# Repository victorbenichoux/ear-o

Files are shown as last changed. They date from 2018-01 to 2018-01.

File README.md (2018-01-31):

<p align="center">
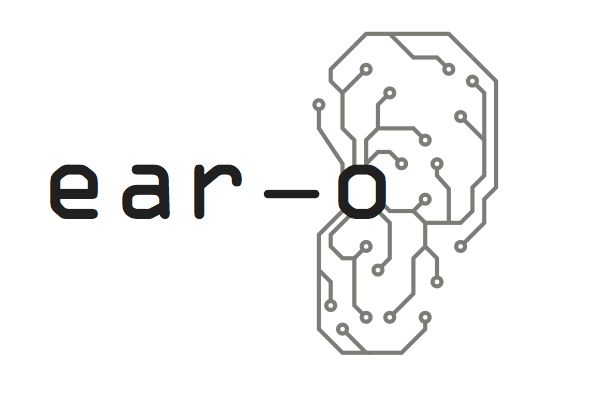
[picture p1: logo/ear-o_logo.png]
Github Logo

</p>

# Project

This project describes a hearing device that can be used as a tool for embedded digital signal processing. It is based on the Ezairo chip series by ON Semi.

## Contents

The repository contains some documentation and two designs:
* A development board
* A wearable earbud

## Built With

* [Eagle CAD](https://www.autodesk.com/products/eagle/overview) - For electronic circuits and board routing.
* [Fusion 360](https://www.autodesk.com/products/fusion-360/overview) - 3D models

## Authors

* **Victor Benichoux** - *electronics and software* - Researcher at [Institut Pasteur](https://research.pasteur.fr/en/member/victor-benichoux/). Contact me if you are interested in this project.
* **Albane Imbert** - *case design* - Head of the [fab lab](https://research.pasteur.fr/en/team/fab-lab/) at Institut Pasteur.

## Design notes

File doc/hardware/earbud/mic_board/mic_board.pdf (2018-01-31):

TITLE | VERSION
AUTHOR | DATE

HISTORY

PAGE | /1 | 1

## MICROPHONE BOARD

VICTOR BENICHOUX

v1.0

v1.0 : Initial release

16/01/2018

# MICP MICN MICS

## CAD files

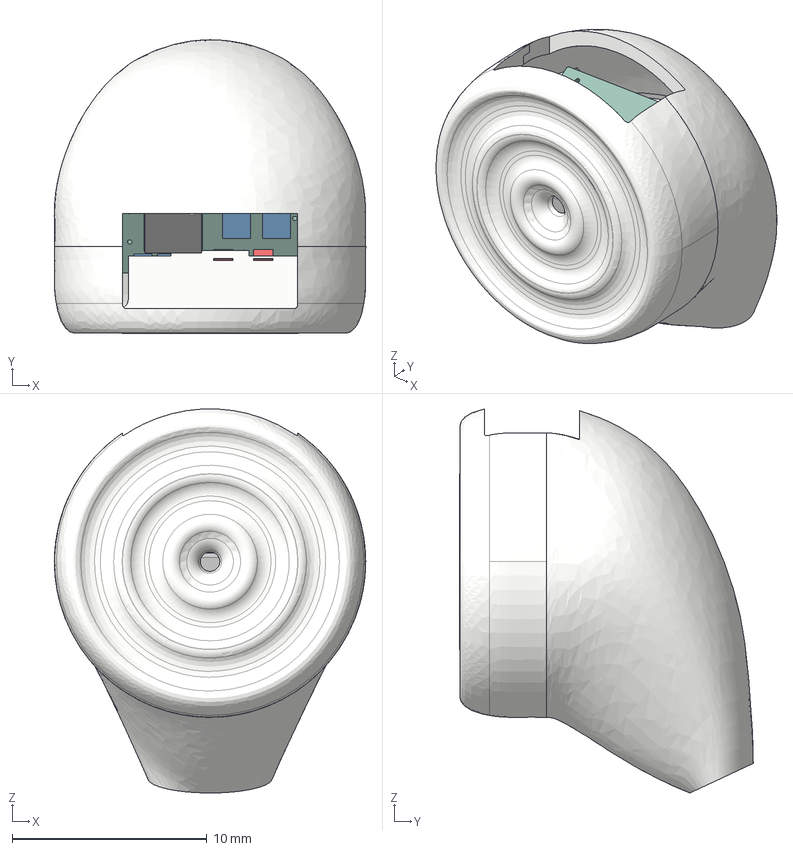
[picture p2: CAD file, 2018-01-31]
src/hardware/earbud/case/full_assembly.step
16.0 x 15.1 x 19.7 mm
Board
E7150-102A49-AG-MOD
ADXL362
220 uF x 2
12ohm x 6
RCVR
TEST-PAD-0.2 x 8
SINGLE-PAD x 12
Board_1
SINGLE-PADSQ x 3
mqm-32325-000_sw_asm(1)
Top Cap
Bottom cap

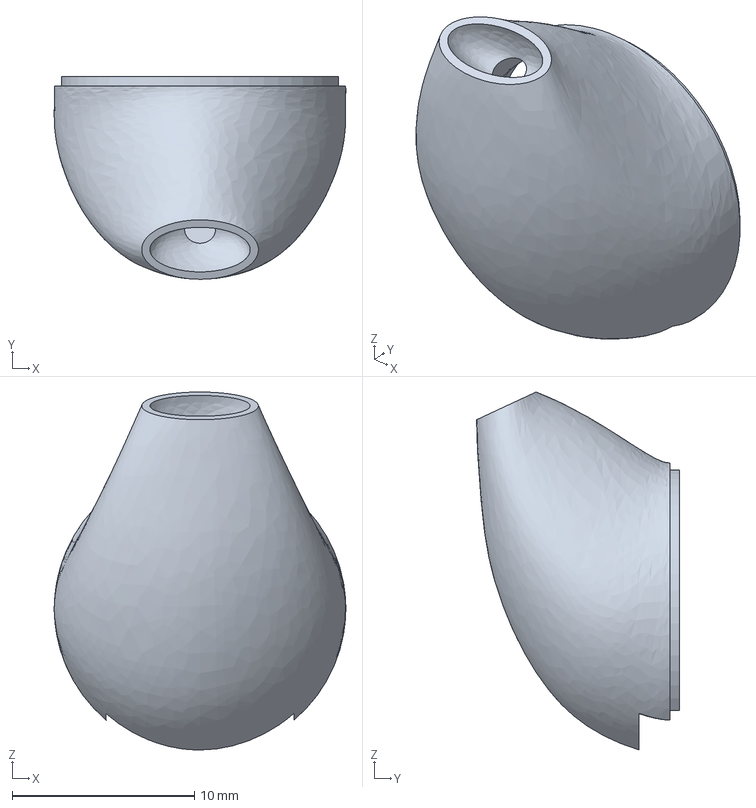
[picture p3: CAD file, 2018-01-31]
src/hardware/earbud/case/bottom_cap.step
16.0 x 11.1 x 19.6 mm

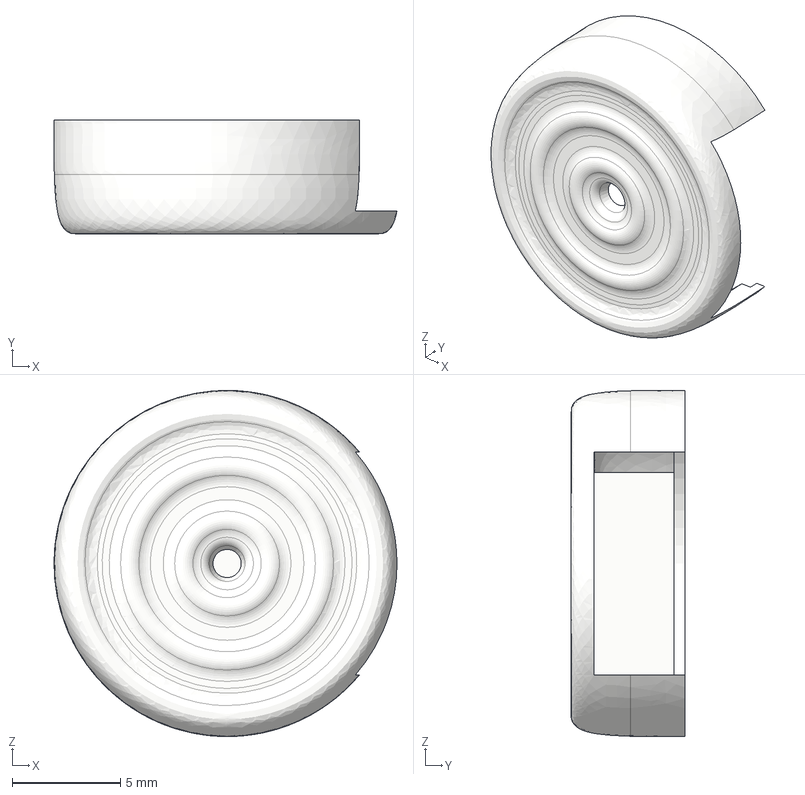
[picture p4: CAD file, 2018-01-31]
src/hardware/earbud/case/top_cap.step
15.9 x 5.27 x 16.0 mm

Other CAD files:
src/hardware/earbud/case/bottom_cap.stl
src/hardware/earbud/case/top_cap.stl

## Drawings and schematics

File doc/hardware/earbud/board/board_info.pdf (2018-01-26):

BOTTOM VIEW | TOP VIEW

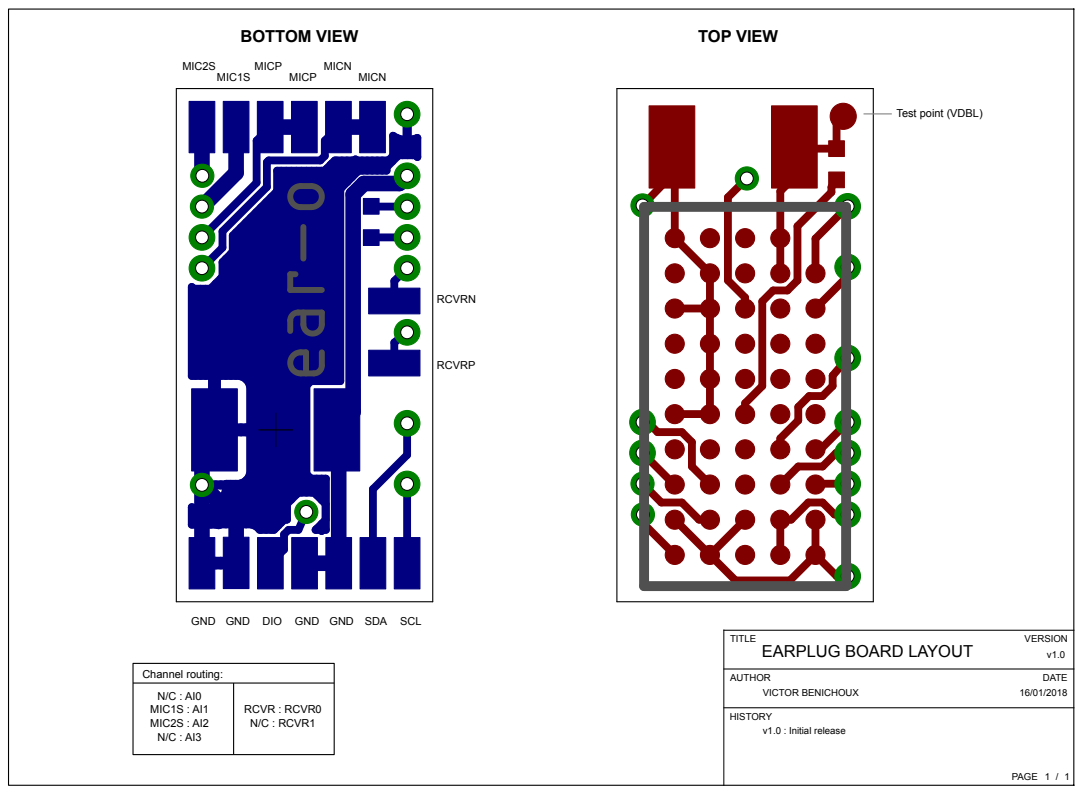
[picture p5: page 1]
TITLE; VERSION; AUTHOR; DATE; HISTORY; PAGE; VICTOR BENICHOUX; v1.0 : Initial release; RCVRP; RCVRN; MIC2S; MIC1S; MICN; MICP; N/C : AI0 MIC1S : AI1 MIC2S : AI2 N/C : AI3; Channel routing:; RCVR : RCVR0 N/C : RCVR1

Test point (VDBL)

GND GND DIO GND GND SDA SCL

EARPLUG BOARD LAYOUT

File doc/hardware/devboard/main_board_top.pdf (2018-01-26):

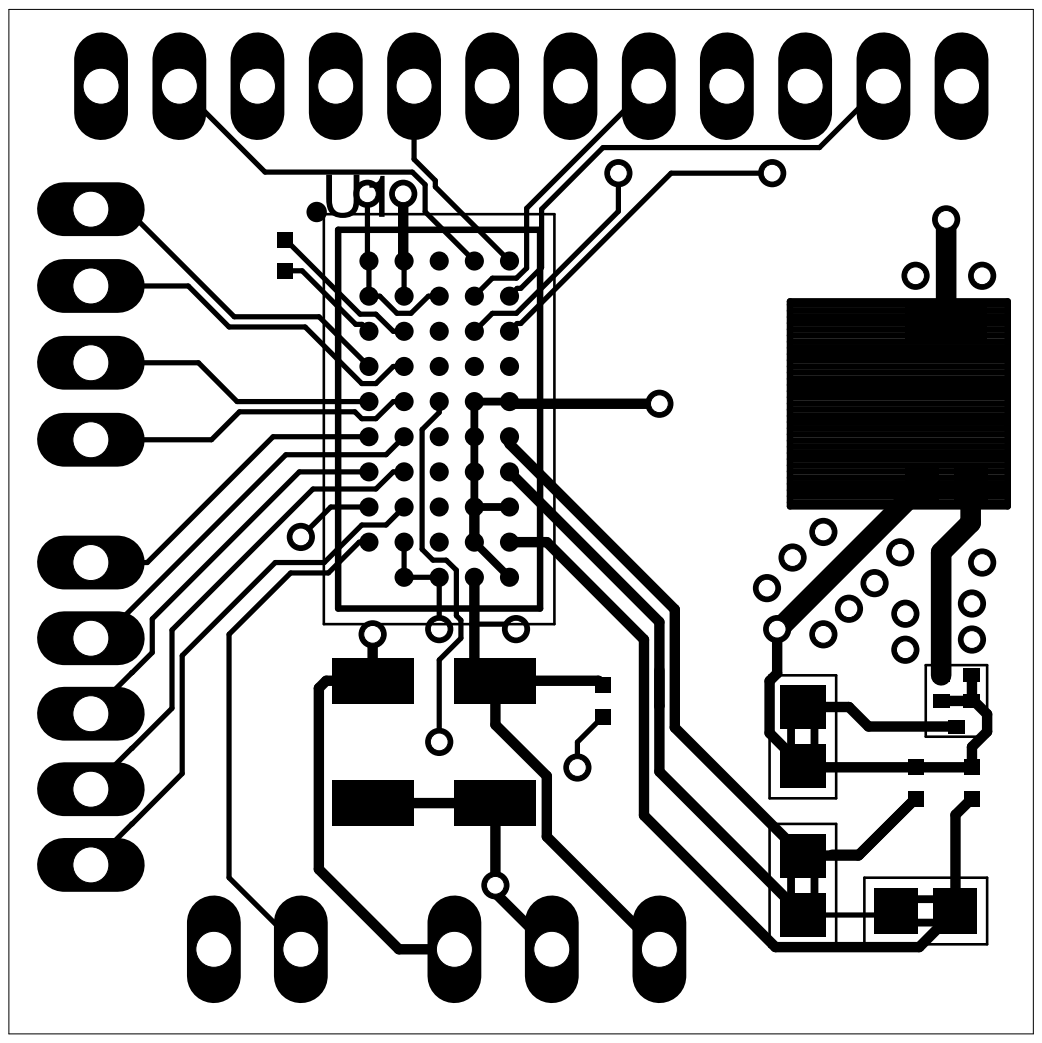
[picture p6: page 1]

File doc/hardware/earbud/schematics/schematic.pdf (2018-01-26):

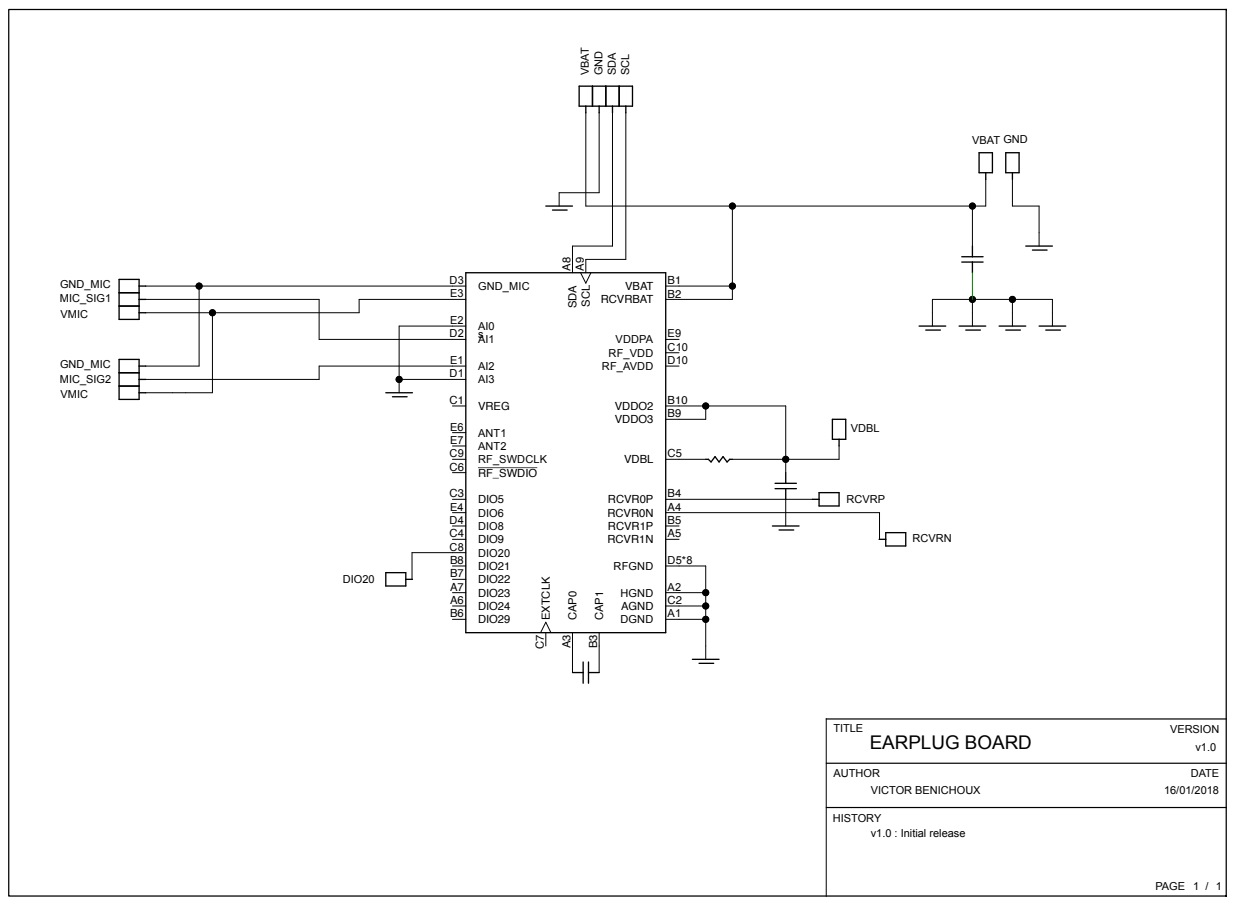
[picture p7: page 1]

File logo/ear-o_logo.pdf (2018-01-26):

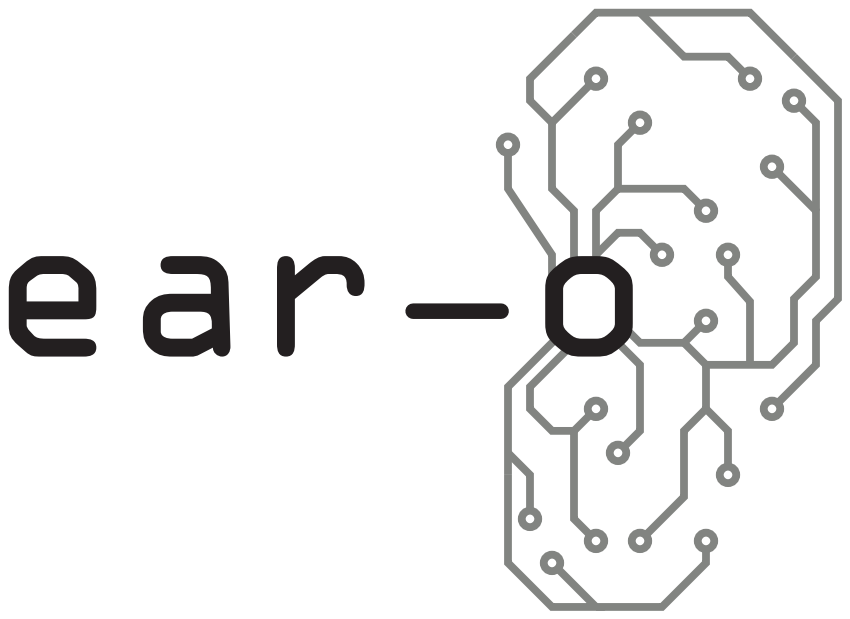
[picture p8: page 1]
ear o ear o

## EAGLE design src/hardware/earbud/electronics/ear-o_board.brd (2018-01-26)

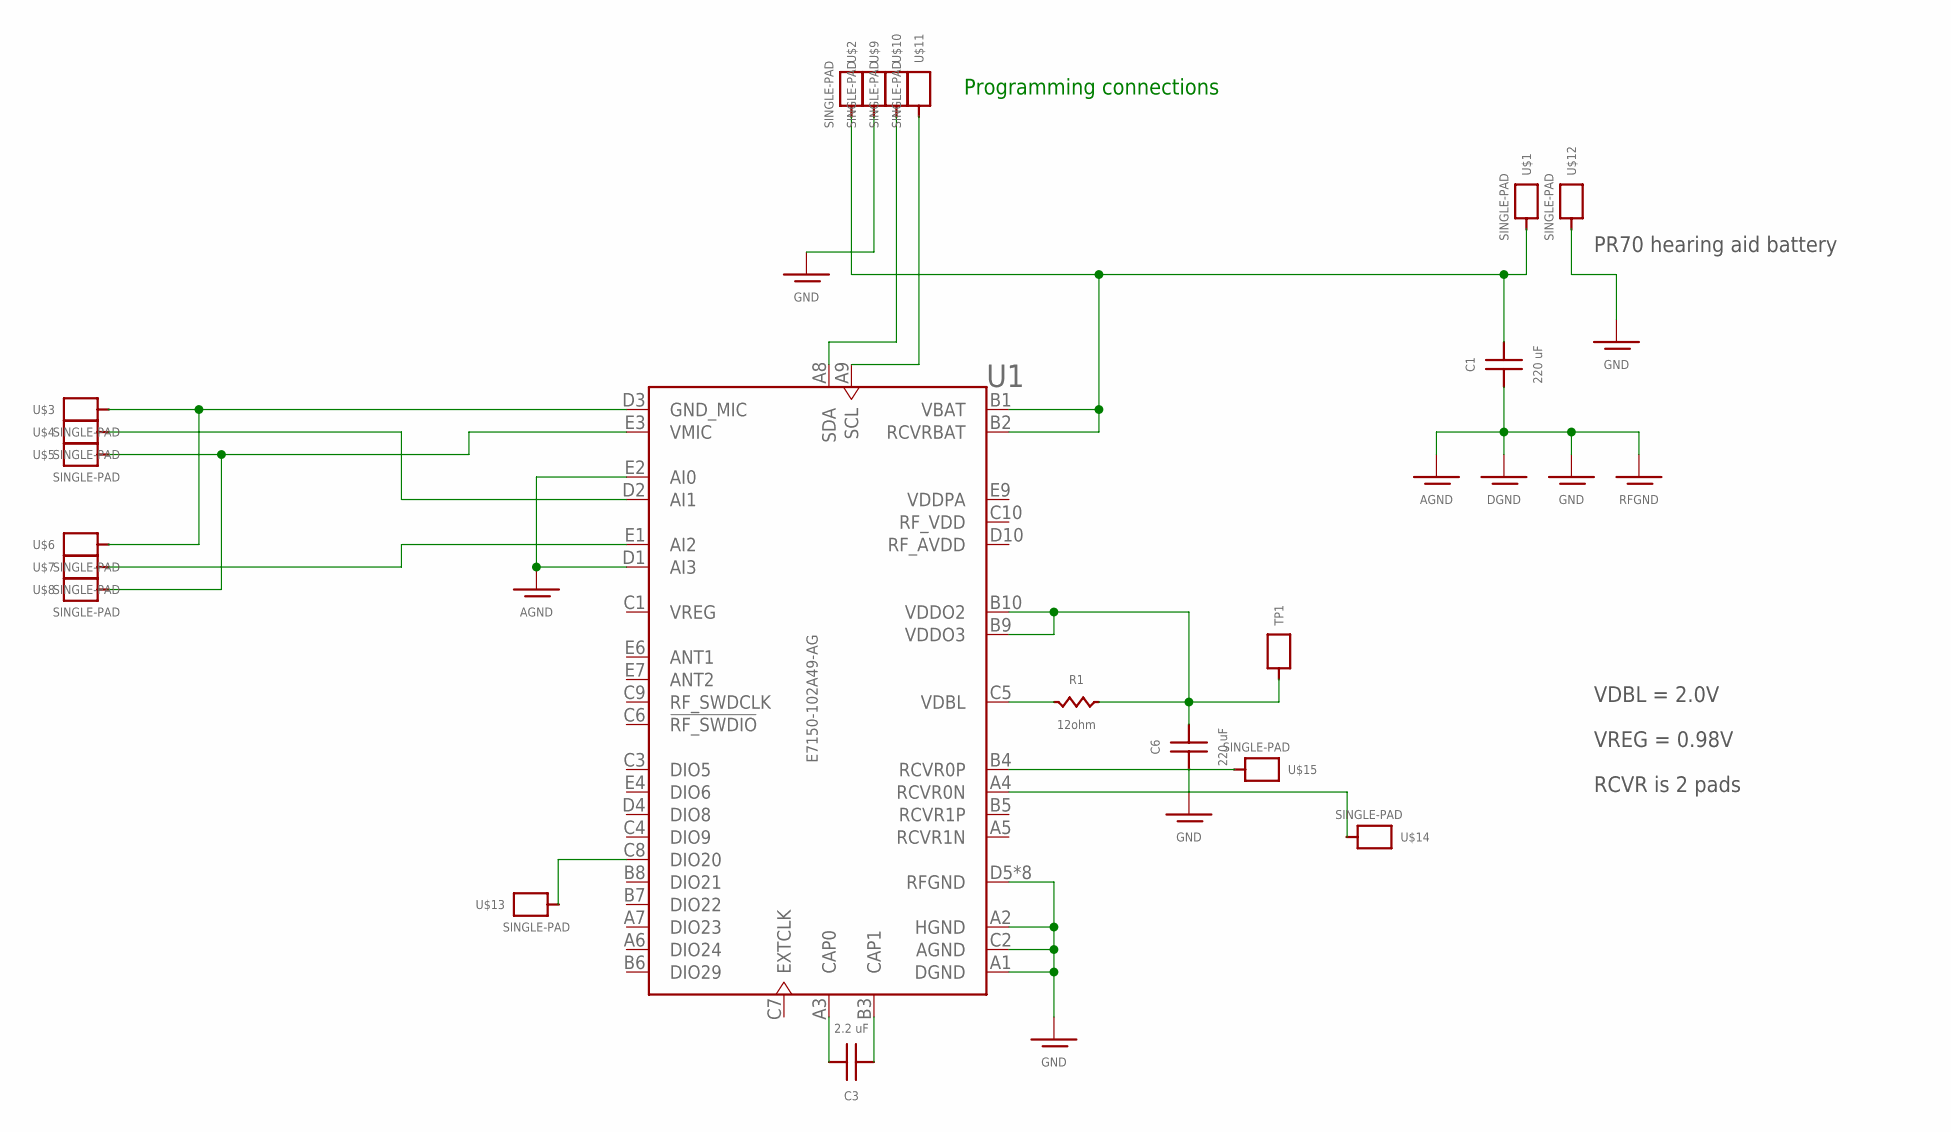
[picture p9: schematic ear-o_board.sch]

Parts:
C1, C6: 220 uF; 1206
C3: 2.2 uF; 0201
R1: 12ohm; 0201
TP1: TEST-POINT; TEST-PAD-0.2
U1: E7150-102A49-AG; BGA49C69P10X5_739X394X178
U$1, U$2, U$3, U$4, U$5, U$6, U$7, U$8, U$9, U$10, U$11, U$12, U$13, U$14, U$15: SINGLE-PAD

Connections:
1.4V: C1.P$2 (2), U1.B1 (VBAT), U1.B2 (RCVRBAT), U$1.P$1, U$2.P$1
GND: C1.P$1 (1), C6.P$1 (1), U1.A1 (DGND), U1.A2 (HGND), U1.C2 (AGND), U1.D1 (AI3), U1.D5 (RFGND), U1.D6 (RFGND), U1.D7 (RFGND), U1.D8 (RFGND), U1.D9 (RFGND), U1.E2 (AI0), U1.E5 (RFGND), U1.E8 (RFGND), U1.E10 (RFGND), U$9.P$1, U$12.P$1
MIC1S: U1.D2 (AI1), U$4.P$1
MIC2S: U1.E1 (AI2), U$7.P$1
MIC-N: U1.D3 (GND_MIC), U$3.P$1, U$6.P$1
MIC-P: U1.E3 (VMIC), U$5.P$1, U$8.P$1
unnamed: U1.C8 (DIO20), U$13.P$1
unnamed: R1.P$1, U1.C5 (VDBL)
unnamed: C3.P$2 (2), U1.A3 (CAP0)
unnamed: C3.P$1 (1), U1.B3 (CAP1)
RCVR0N: U1.A4 (RCVR0N), U$14.P$1
RCVR0P: U1.B4 (RCVR0P), U$15.P$1
RF_AVDD: U1.D10 (RF_AVDD)
RF_VDD: U1.C10 (RF_VDD)
SCL: U1.A9 (SCL), U$11.P$1
SDA: U1.A8 (SDA), U$10.P$1
VDBL: C6.P$2 (2), R1.P$2, TP1.P, U1.B9 (VDDO3), U1.B10 (VDDO2)
VDDPA: U1.E9 (VDDPA)
VREG: U1.C1 (VREG)

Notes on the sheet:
VDBL = 2.0V
VREG = 0.98V
PR70 hearing aid battery
RCVR is 2 pads
Programming connections

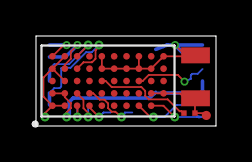
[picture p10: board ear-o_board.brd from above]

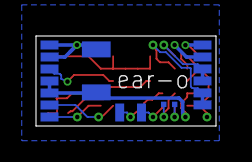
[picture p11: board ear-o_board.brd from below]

Board: 4 copper layers, 10.0 x 5.0 mm, 21 parts (17 on the bottom side), 15 nets.

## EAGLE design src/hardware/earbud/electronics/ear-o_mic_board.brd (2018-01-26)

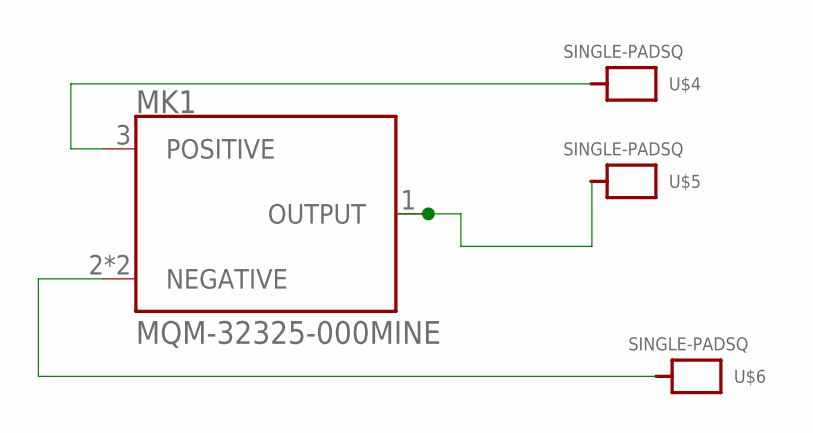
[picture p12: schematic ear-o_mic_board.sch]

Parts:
MK1: MQM-32325-000MINE; MIC_MINE
U$4, U$5, U$6: SINGLE-PADSQ; SQUAREPAD0.8

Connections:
NEG: MK1.2 (NEGATIVE), MK1.P$1 (NEGATIVE), U$6.P$1
POS: MK1.3 (POSITIVE), U$4.P$1
SIG: MK1.1 (OUTPUT), U$5.P$1

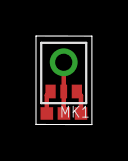
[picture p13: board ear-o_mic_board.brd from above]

Board: 1 copper layer, 3.1 x 4.9 mm, 4 parts (0 on the bottom side), 3 nets.

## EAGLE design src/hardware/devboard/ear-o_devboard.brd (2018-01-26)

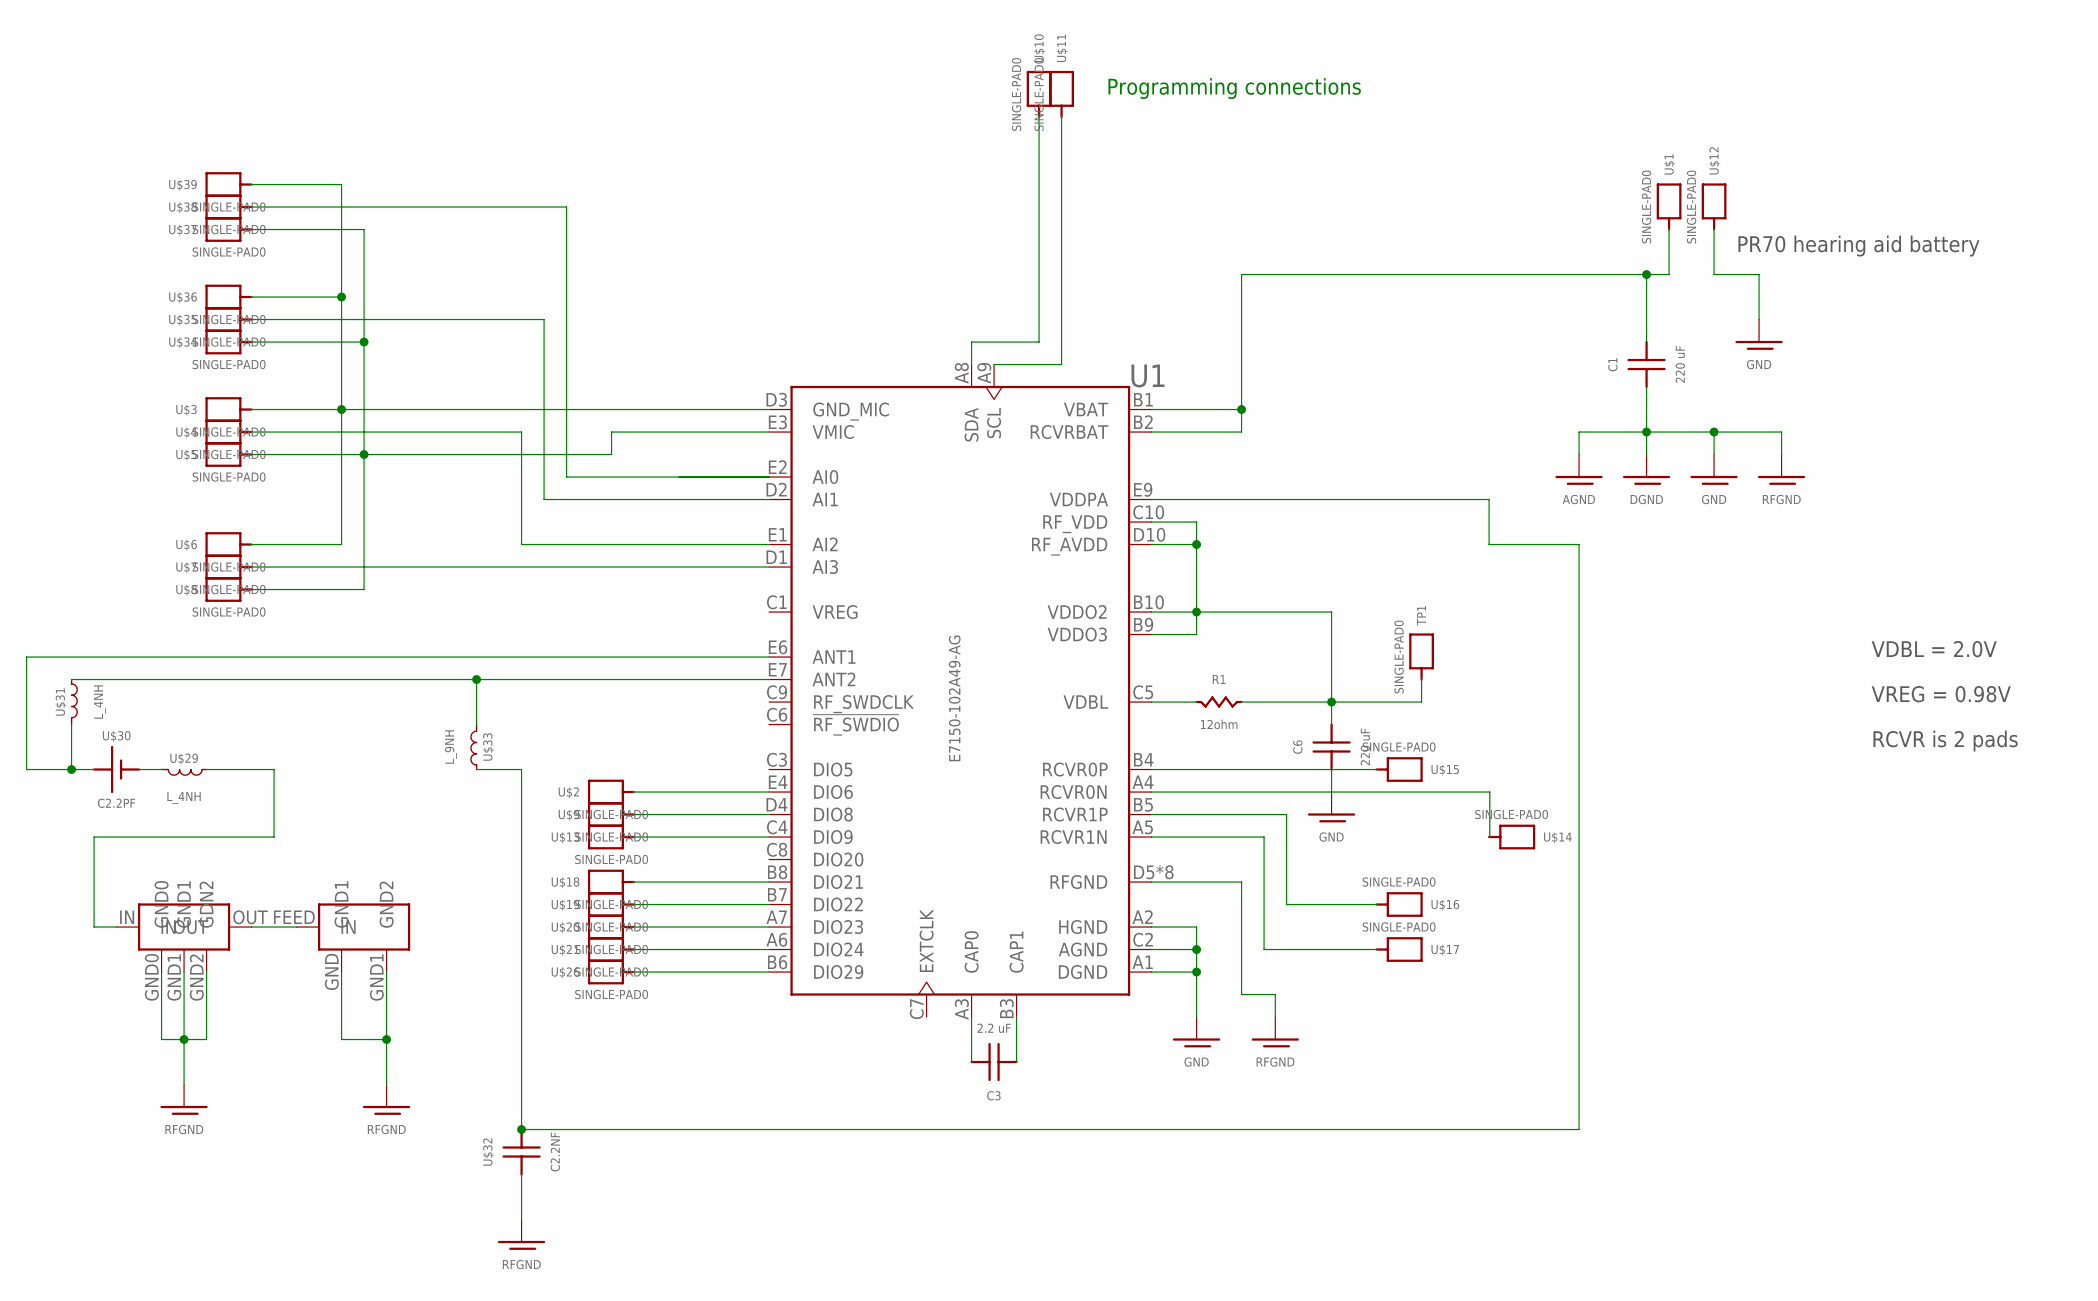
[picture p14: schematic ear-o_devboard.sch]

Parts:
C1, C6: 220 uF; 1206
C3: 2.2 uF; 0201
R1: 12ohm; 0201
TP1: SINGLE-PAD0; TH
U1: E7150-102A49-AG; BGA49C69P10X5_739X394X178
U$1, U$2, U$3, U$4, U$5, U$6, U$7, U$8, U$9, U$10, U$11, U$12, U$13, U$14, U$15, U$16, U$17, U$18, U$19, U$20, U$21, U$26, U$34, U$35, U$36, U$37, U$38, U$39: SINGLE-PAD0; TH
U$27: CHIP_ANT; W3008
U$28: RF_FILT; BPFILT
U$29, U$31: L_4NH; 0402
U$30: C2.2PF; 0201
U$32: C2.2NF; 0201
U$33: L_9NH; 0402

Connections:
1.4V: C1.P$2 (2), U1.B1 (VBAT), U1.B2 (RCVRBAT), U$1.P$1
DIO6: U1.E4 (DIO6), U$2.P$1
DIO8: U1.D4 (DIO8), U$9.P$1
DIO9: U1.C4 (DIO9), U$13.P$1
DIO21: U1.B8 (DIO21), U$18.P$1
DIO22: U1.B7 (DIO22), U$19.P$1
DIO23: U1.A7 (DIO23), U$20.P$1
DIO24: U1.A6 (DIO24), U$21.P$1
DIO29: U1.B6 (DIO29), U$26.P$1
MIC0S: U1.E2 (AI0), U$38.P$1
MIC1S: U1.D2 (AI1), U$35.P$1
MIC2S: U1.E1 (AI2), U$4.P$1
MIC3S: U1.D1 (AI3), U$7.P$1
MIC-N: U1.D3 (GND_MIC), U$3.P$1, U$6.P$1, U$36.P$1, U$39.P$1
MIC-P: U1.E3 (VMIC), U$5.P$1, U$8.P$1, U$34.P$1, U$37.P$1
unnamed: R1.P$1, U1.C5 (VDBL)
unnamed: C3.P$2 (2), U1.A3 (CAP0)
unnamed: C3.P$1 (1), U1.B3 (CAP1)
unnamed: U$27.FEED (IN), U$28.OUT
unnamed: U$28.IN, U$29.1
unnamed: U1.E9 (VDDPA), U$32.P$2 (2), U$33.1
unnamed: U1.E7 (ANT2), U$31.1, U$33.2
P1.4V: U1.E6 (ANT1), U$30.P$2 (P1.4V), U$31.2
RCVR0N: U1.A4 (RCVR0N), U$14.P$1
RCVR0P: U1.B4 (RCVR0P), U$15.P$1
RCVR1N: U1.A5 (RCVR1N), U$17.P$1
RCVR1P: U1.B5 (RCVR1P), U$16.P$1
RFGND: C1.P$1 (1), C6.P$1 (1), U1.A1 (DGND), U1.A2 (HGND), U1.C2 (AGND), U1.D5 (RFGND), U1.D6 (RFGND), U1.D7 (RFGND), U1.D8 (RFGND), U1.D9 (RFGND), U1.E5 (RFGND), U1.E8 (RFGND), U1.E10 (RFGND), U$12.P$1, U$27.GND (GND1), U$27.GND1 (GND2), U$28.GND0, U$28.GND1, U$28.GND2 (GDN2), U$29.2, U$30.P$1 (GND), U$32.P$1 (1)
SCL: U1.A9 (SCL), U$11.P$1
SDA: U1.A8 (SDA), U$10.P$1
VDBL: C6.P$2 (2), R1.P$2, TP1.P$1, U1.B9 (VDDO3), U1.B10 (VDDO2), U1.C10 (RF_VDD), U1.D10 (RF_AVDD)
VREG: U1.C1 (VREG)

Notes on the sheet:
VDBL = 2.0V
VREG = 0.98V
PR70 hearing aid battery
RCVR is 2 pads
Programming connections

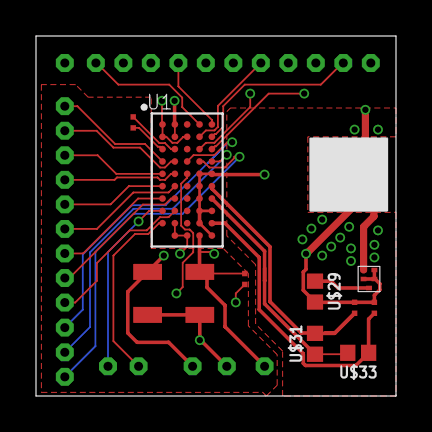
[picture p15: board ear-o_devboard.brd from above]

Board: 4 copper layers, 20.0 x 20.0 mm, 41 parts (0 on the bottom side), 31 nets.

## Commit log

2018-01-31 Added initial case design files
    [bottom_cap.step, bottom_cap.stl, ear-o_board.brd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]
2018-01-31 moved the electronics to a new folder
    [ear-o_board.brd, ear-o_board.sch, ear-o_mic_board.brd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]
2018-01-31 Updated the mic board datasheet
